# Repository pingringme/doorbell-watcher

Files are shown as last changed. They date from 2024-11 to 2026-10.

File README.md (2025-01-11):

# PingRing.me - Smart Doorbell

## 🌟 About PingRing.me

PingRing.me modernizes your existing doorbell by adding notifications via SMS, WhatsApp, HTTP, MQTT, and more. This enhancement ensures you never miss a visitor, whether you're outside or wearing noise-canceling headphones. The system integrates seamlessly with your current doorbell setup, allowing you to track arrivals and receive timely notifications.

## 🛠️ Features

- **Multi-Channel Notifications:** Receive alerts through SMS, WhatsApp, HTTP, MQTT, etc.
- **Seamless Integration:** Compatible with existing doorbell systems.
- **Local Web Server:** Access device information and perform over-the-air updates.
- **Open Source:** Hardware designs and code are publicly available.

## 📸 Visuals

Check [website here https://pingring.me](https://pingring.me)

## 🛠️ Tech Stack

- **Microcontroller:** ESP32-PICO-D4
- **Programming Language:** C (Arduino)
- **Cloud Functions:** AWS Lambda (Python)
- **Hardware Platform:** [TinyPICO USB-C](https://www.tinypico.com)

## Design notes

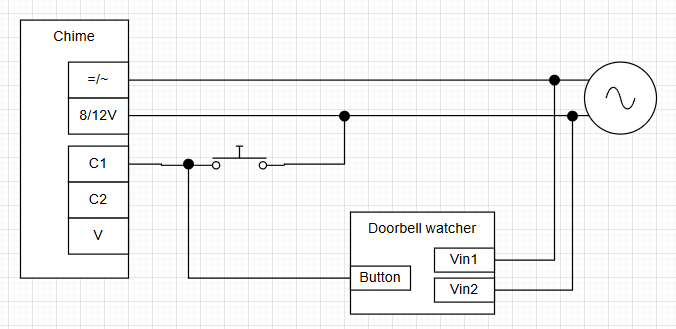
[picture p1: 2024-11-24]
docs/system_diagram.png

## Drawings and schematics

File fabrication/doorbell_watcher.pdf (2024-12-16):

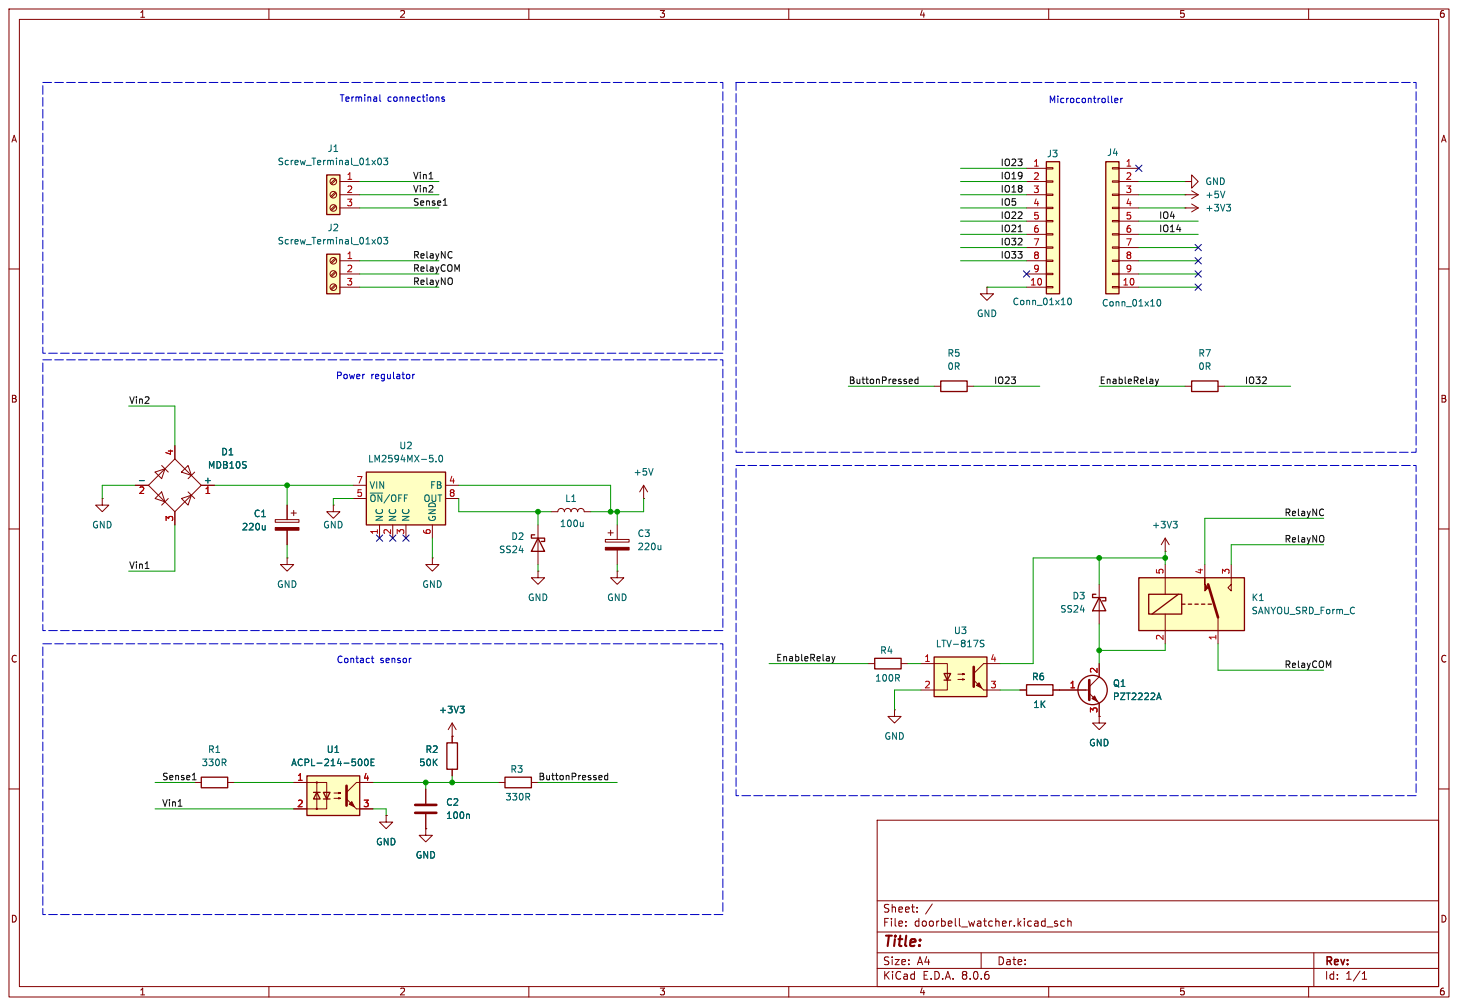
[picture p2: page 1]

3 FB 4 ~{ON}/OFF 5 GND

Id: 1/1 Title: File: doorbell_watcher.kicad_sch Sheet: /

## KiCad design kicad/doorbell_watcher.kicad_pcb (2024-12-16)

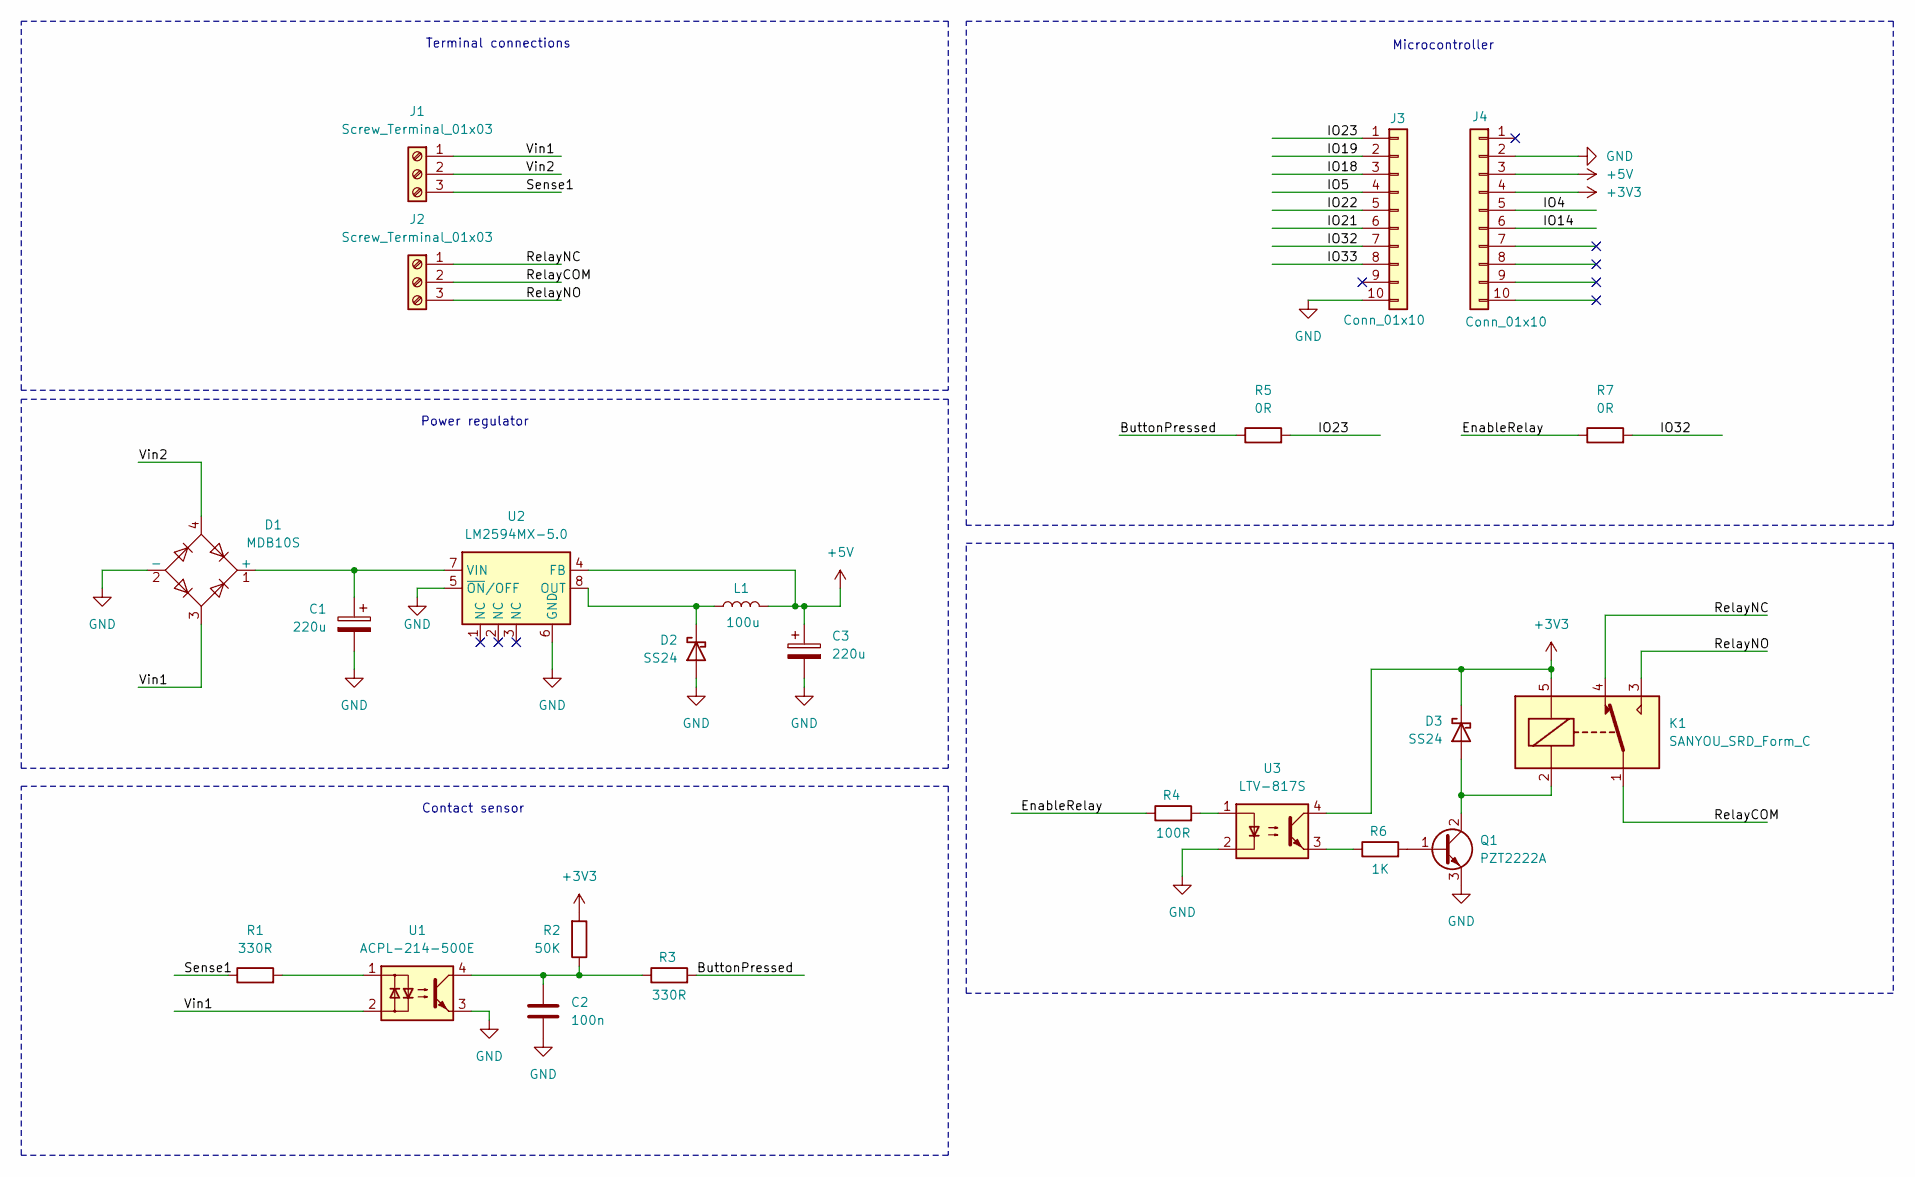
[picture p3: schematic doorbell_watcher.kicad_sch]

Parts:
C1, C3: 220u; CAP_FT_F_PAN-M; LCSC C178594
C2: 100n; C_0805_2012Metric_Pad1.18x1.45mm_HandSolder; LCSC C49678
D1: MDB10S; TSSOP4-MICRO-DIP_948BS_ONS-M; LCSC C258169
D2, D3: SS24; DO-214AC(SMA); LCSC C211773
J1, J2: Screw_Terminal_01x03; screw_connector_1x3; LCSC C589616
J3, J4: Conn_01x10; 10-pin header; LCSC C225507
K1: SANYOU_SRD_Form_C; Relay_SPDT_SANYOU_SRD_Series_Form_C; LCSC C24585
L1: 100u; IND_829SNLT_PUL; LCSC C2453068
Q1: PZT2222A; SOT-223-3_TabPin2; LCSC C115272
R1, R3: 330R; R_0805_2012Metric_Pad1.20x1.40mm_HandSolder; LCSC C17630
R2: 50K; R_0805_2012Metric_Pad1.20x1.40mm_HandSolder; LCSC C2828840
R4: 100R; R_0805_2012Metric_Pad1.20x1.40mm_HandSolder; LCSC C17408
R5, R7: 0R; R_0805_2012Metric_Pad1.20x1.40mm_HandSolder; LCSC C17477
R6: 1K; R_0805_2012Metric_Pad1.20x1.40mm_HandSolder; LCSC C95781
U1: ACPL-214-500E; SOP-4_4.4x2.6mm_P1.27mm; LCSC C5361360
U2: LM2594MX-5.0; SOIC-8_3.9x4.9mm_P1.27mm; LCSC C35323
U3: LTV-817S; SMDIP-4_W9.53mm; LCSC C125121

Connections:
+3V3: D3.1 (K), J4.4, K1.5, R2.2, U3.4
+5V: C3.1, J4.3, L1.2, U2.4 (FB)
/ButtonPressed: R3.2, R5.1
/EnableRelay: R4.1, R7.1
/IO4: J4.5
/IO5: J3.4
/IO14: J4.6
/IO18: J3.3
/IO19: J3.2
/IO21: J3.6
/IO22: J3.5
/IO23: J3.1, R5.2
/IO32: J3.7, R7.2
/IO33: J3.8
/RelayCOM: J2.2, K1.1
/RelayNC: J2.1, K1.4
/RelayNO: J2.3, K1.3
/Sense1: J1.3, R1.1
/Vin1: D1.3, J1.1, U1.2
/Vin2: D1.4, J1.2
GND: C1.2, C2.2, C3.2, D1.2 (-), D2.2 (A), J3.10, J4.2, Q1.3 (E), U1.3, U2.5 (~ON/OFF), U2.6 (GND), U3.2
unnamed: C2.1, R2.1, R3.1, U1.4
unnamed: C1.1, D1.1 (+), U2.7 (VIN)
unnamed: D2.1 (K), L1.1, U2.8 (OUT)
unnamed: D3.2 (A), K1.2, Q1.2 (C)
unnamed: Q1.1 (B), R6.2
unnamed: R1.2, U1.1
unnamed: R4.2, U3.1
unnamed: R6.1, U3.3

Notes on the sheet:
Contact sensor
Terminal connections
Microcontroller
Power regulator

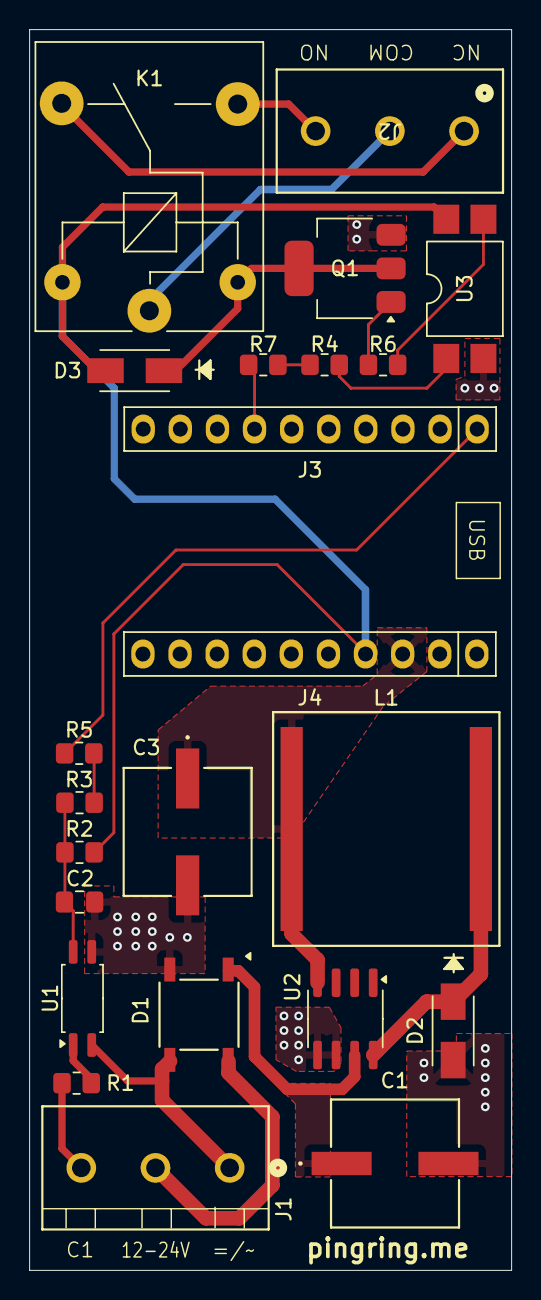
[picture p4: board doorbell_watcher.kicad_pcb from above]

Board: 2 copper layers, 33.0 x 84.9 mm, 23 parts (0 on the bottom side), 21 nets.

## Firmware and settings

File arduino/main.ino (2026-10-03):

#include <HTTP_Method.h>
#include <Uri.h>
#include <NetworkClient.h>
#include <TinyPICO.h>
#include <WiFi.h>
#include <WebServer.h>
#include <HTTPClient.h>
#include <ESPmDNS.h>
#include <ElegantOTA.h>
#include <PubSubClient.h>
#include <WiFiClientSecure.h>
#include "esp_netif.h"
#include "time.h"
#include "config.h"

// (all configuration constants are now defined in config.h)

// instances
TinyPICO tp = TinyPICO();
WebServer server(80);
WiFiClient espClient;
PubSubClient mqttClient(espClient);

// variables
IPAddress mqttServerIP;
// Fixed-size buffers (no heap allocation): "YYYY-MM-DD HH:MM:SS" = 19 chars
// + null terminator + safety margin.
char startupDateTime[24] = "n/a";
char lastRelayDateTime[24] = "never";
bool isConfigured = false;
int mqttRetries = 0;
int wifiRetries = 0;
int bellPresses = 0;
int mqttDiscoverySent = 0;
bool isSilenced = false;
unsigned long lastRelayTime = 0;
unsigned long lastHttpTime = 0;
unsigned long lastMqttReconnectAttempt = 0;
int relayActivations = 0;
// Mirror-mode relay state: while the physical bell button is held down, the
// relay is held HIGH. These are written by relaySetOn/relaySetOff (called
// from pollBellButton) and read by the safety force-off check.
bool relayOn = false;
unsigned long relayOnSince = 0;
// Deferred-HTTP flag: set on a press edge when the cooldown allows it, and
// consumed AFTER pollBellButton() so the release edge can be observed before
// the blocking HTTPS call is made. This keeps short presses from holding the
// relay on for the full HTTP timeout window.
bool httpSendPending = false;

String getMacAddress() {
    uint8_t mac[6];
    WiFi.macAddress(mac); // Get MAC address as an array
    
    // Convert MAC array to string format
    char macStr[18];
    snprintf(macStr, sizeof(macStr), "%02X:%02X:%02X:%02X:%02X:%02X",
             mac[0], mac[1], mac[2], mac[3], mac[4], mac[5]);

    return String(macStr);
}

String getTimeString() {
    struct tm timeinfo;
    if (!getLocalTime(&timeinfo)) {
        return "Failed to obtain time";
    }

    char timeStr[16];
    strftime(timeStr, sizeof(timeStr), "%H:%M:%S", &timeinfo);
    
    return String(timeStr);
}

String getDateString() {
    struct tm timeinfo;
    if (!getLocalTime(&timeinfo)) {
        return "Failed to obtain date";
    }

    char dateStr[16];
    strftime(dateStr, sizeof(dateStr), "%Y-%m-%d", &timeinfo); // Format: YYYY-MM-DD

    return String(dateStr);
}

String getFreeMemoryString() {
    int freeHeap = ESP.getFreeHeap();  // Get free heap memory in bytes
    return String(freeHeap);
}

// Block (up to timeoutMs) until the system clock has been synced via NTP.
// Returns true if time was obtained.
bool waitForTimeSync(uint32_t timeoutMs) {
    struct tm timeinfo;
    return getLocalTime(&timeinfo, timeoutMs);
}

// Fill a fixed-size buffer with the current local date+time as
// "YYYY-MM-DD HH:MM:SS". Falls back to "n/a" if the clock is not synced.
// Avoids any heap allocation, so it's safe to call indefinitely.
void fillDateTimeString(char* buf, size_t bufSize) {
    struct tm timeinfo;
    if (!getLocalTime(&timeinfo)) {
        snprintf(buf, bufSize, "n/a");
        return;
    }
    strftime(buf, bufSize, "%Y-%m-%d %H:%M:%S", &timeinfo);
}

// DHCP lease renewals overwrite DNS, so this is re-applied before every HTTPS request.
void applyDnsOverride() {
  IPAddress primary, secondary;
  if (!primary.fromString(dns_override_primary)) {
    return;
  }
  esp_netif_dns_info_t dns = {};
  dns.ip.type = ESP_IPADDR_TYPE_V4;
  dns.ip.u_addr.ip4.addr = static_cast<uint32_t>(primary);
  esp_netif_set_dns_info(WiFi.STA.netif(), ESP_NETIF_DNS_MAIN, &dns);
  if (secondary.fromString(dns_override_secondary)) {
    dns.ip.u_addr.ip4.addr = static_cast<uint32_t>(secondary);
    esp_netif_set_dns_info(WiFi.STA.netif(), ESP_NETIF_DNS_BACKUP, &dns);
  }
}

void setup() {
  // booting up with blue as initial color
  tp.DotStar_SetPixelColor(0, 0, 255);  //Blue
  // serial setup
  Serial.begin(115200);
  Serial.println("*************");
  Serial.println("Booting up...");
  // pins setup
  configureIO();
  // wifi setup
  watchWifi();
  // mDNS
  configureMDNS();
  // mqtt
  configureMQTT();
  // web server
  configureWebServer();
  // configure time
  configTime(gmtOffset_sec, daylightOffset_sec, ntpServer);
  // wait for NTP to actually sync before stamping startupDateTime; otherwise
  // the stored value would be "Failed to obtain ..." on a cold boot.
  if (!waitForTimeSync(NTP_SYNC_TIMEOUT_MS)) {
    Serial.println("Warning: NTP sync timed out.");
  }
  // standard initial sleep...
  Serial.println("finishing initial setup()...");
  // print time
  fillDateTimeString(startupDateTime, sizeof(startupDateTime));
  Serial.println(startupDateTime);
  // delay after setup
  delay(SLEEP_AFTER_SETUP_MS);
  // release
  isConfigured = true;
}
String enabledBadge(bool enabled) {
  return enabled ? "<span class=\"badge bg-success\">enabled</span>"
                 : "<span class=\"badge bg-secondary\">disabled</span>";
}

// "***" is the placeholder used for secrets in the committed config.h.
bool isSecretSet(const char* value) {
  return strlen(value) > 0 && strcmp(value, "***") != 0;
}

// base URL handling
void handle_base() {
  Serial.println("ESP32 Web Server: New request received...");  // for debugging
  Serial.println("GET /");                                      // for debugging
 
  // response
  String page = html_template_main;
  // variables 
  page.replace("{{firmware}}", FIRMWARE_VERSION);
  page.replace("{{startup}}", startupDateTime);
  page.replace("{{now}}", getDateString() + " "+ getTimeString());
  page.replace("{{heap}}", getFreeMemoryString());

  page.replace("{{ssid}}", WiFi.SSID());
  page.replace("{{ip}}", WiFi.localIP().toString());
  page.replace("{{rssi}}", String(WiFi.RSSI()) + " dBm");
  page.replace("{{mac}}", getMacAddress());
  page.replace("{{dns}}", WiFi.dnsIP(0).toString() + ", " + WiFi.dnsIP(1).toString() +
                          (strlen(dns_override_primary) > 0 ? " (override)" : " (DHCP)"));

  page.replace("{{mqtt_server}}", "mqtt://" + String(mqtt_auth_user) + ":***@" + mqttServerIP.toString() + ":" + String(mqtt_port));
  page.replace("{{mqtt_connected}}", mqttClient.connected() ? "true" : "false");
  page.replace("{{mqtt_retries}}", String(mqttRetries));
  page.replace("{{mqtt_discovery}}", String(mqttDiscoverySent));

  page.replace("{{wifi_retries}}", String(wifiRetries));
  page.replace("{{bell_presses}}", String(bellPresses));
  page.replace("{{relay_activations}}", String(relayActivations));
  page.replace("{{relay_last}}", lastRelayDateTime);
  page.replace("{{silence_mode}}", isSilenced ? "true" : "false");

  page.replace("{{cfg_mqtt}}", enabledBadge(mqtt_enabled));
  page.replace("{{cfg_aws}}", enabledBadge(notify_aws_enabled));
  page.replace("{{cfg_telegram}}", enabledBadge(notify_telegram_enabled));
  page.replace("{{cfg_telegram_token}}", isSecretSet(TELEGRAM_BOT_TOKEN) ? "set" : "missing");
  page.replace("{{cfg_telegram_chat}}", isSecretSet(TELEGRAM_CHAT_ID) ? TELEGRAM_CHAT_ID : "missing");
 
  // never cache this status page: values change constantly
  server.sendHeader("Cache-Control", "no-store");
  server.send(200, "text/html", page);
}

// silence mode URL handling
void handle_silence() {
  Serial.println("ESP32 Web Server: Toggling silence...");
  Serial.println("GET /silence");
  // send browser/client result
  server.send(200, "application/json", "{\"action\":\"silence\",\"result\":true}");
  // switch settings
  toggleSilence();
}

// relay URL handling
void handle_relay() {
  Serial.println("ESP32 Web Server: Activating relay...");
  Serial.println("GET /relay");
  // send browser/client result
  server.send(200, "application/json", "{\"action\":\"relay\",\"result\":true}");
  // relay trigger (fixed-duration pulse: no physical press to mirror)
  pulseRelay();
}
// button URL handling
void handle_button() {
  Serial.println("ESP32 Web Server: Activating button...");
  Serial.println("GET /button");
  // send browser/client result
  server.send(200, "application/json", "{\"action\":\"button\",\"result\":true}");
  // button trigger
  activateButton("http");
}
// not found
void handle_NotFound() {
  server.send(404, "text/plain", "Not found");
}
void handle_restart() {
  Serial.println("arduino/esp32 - restart requested...");
  ESP.restart();
}
// Resolve the broker hostname via mDNS. Returns true if a valid (non-zero) IP
// was obtained. mqttServerIP is updated either way.
bool resolveMqttBroker() {
  if (strlen(mqtt_server_hostname_mdns) == 0 || mqtt_port <= 0) {
    return false;
  }
  mqttServerIP = MDNS.queryHost(mqtt_server_hostname_mdns);
  if (mqttServerIP == IPAddress(0, 0, 0, 0)) {
    Serial.print("mDNS lookup failed for ");
    Serial.println(mqtt_server_hostname_mdns);
    return false;
  }
  Serial.print("MQTT broker resolved: ");
  Serial.println(mqttServerIP);
  return true;
}

// Shared Home Assistant MQTT discovery "device" sub-object. Identical
// across every entity belonging to this device, so factored out to keep
// the discovery payloads honest about that fact.
static String mqttDeviceObject() {
  return String("\"device\":{\"identifiers\":[\"") + mqtt_device_id +
         "\"],\"manufacturer\":\"PingRing.me\",\"model\":\"PingRing Board\",\"name\":\"PingRing\"}";
}

// Publish Home Assistant MQTT discovery payloads. Caller must ensure the
// client is connected.
void publishMqttDiscovery() {
  String discovery_payload;
  // discovery for STATE
  discovery_payload = "{";
  discovery_payload += "\"name\": \"Doorbell\",";
  discovery_payload += "\"unique_id\": \"" + String(mqtt_unique_id) + "\",";
  discovery_payload += "\"state_topic\": \"" + String(mqtt_topic_state) + "\",";
  discovery_payload += "\"json_attributes_topic\": \"" + String(mqtt_topic_attributes) + "\",";
  discovery_payload += "\"device_class\": \"occupancy\",";
  discovery_payload += "\"payload_on\": \"ON\",";
  discovery_payload += "\"payload_off\": \"OFF\",";
  discovery_payload += "\"availability_topic\": \"" + String(mqtt_topic_availability) + "\",";
  discovery_payload += "\"payload_available\": \"online\",";
  discovery_payload += "\"payload_not_available\": \"offline\",";
  discovery_payload += mqttDeviceObject();
  discovery_payload += "}";
  mqttClient.publish(mqtt_topic_discovery_state, discovery_payload.c_str(), true);
  mqttDiscoverySent++;
  // discovery for COUNT
  discovery_payload = "{";
  discovery_payload += "\"name\": \"Presses\",";
  discovery_payload += "\"unique_id\": \"" + String(mqtt_unique_id) + "_count\",";
  discovery_payload += "\"state_topic\": \"" + String(mqtt_topic_count) + "\",";
  discovery_payload += "\"unit_of_measurement\": \"presses\",";
  discovery_payload += "\"state_class\": \"total_increasing\",";
  discovery_payload += mqttDeviceObject();
  discovery_payload += "}";
  mqttClient.publish(mqtt_topic_discovery_count, discovery_payload.c_str(), true);
  mqttDiscoverySent++;
}

// Non-blocking connect/reconnect attempt. Rate-limited via
// MQTT_RECONNECT_INTERVAL_MS. Returns true if connected after the call.
bool ensureMqttConnected() {
  if (!mqtt_enabled) {
    return false;
  }
  if (mqttClient.connected()) {
    return true;
  }
  unsigned long now = millis();
  if (lastMqttReconnectAttempt != 0 &&
      (now - lastMqttReconnectAttempt) < MQTT_RECONNECT_INTERVAL_MS) {
    return false;
  }
  lastMqttReconnectAttempt = now;

  // Re-resolve the broker every time we attempt to reconnect; the IP may
  // have changed and the previous lookup may have failed.
  if (!resolveMqttBroker()) {
    return false;
  }
  mqttClient.setServer(mqttServerIP, mqtt_port);
  mqttClient.setBufferSize(1024);

  mqttRetries++;
  Serial.print("MQTT connecting (attempt ");
  Serial.print(mqttRetries);
  Serial.println(")...");
  if (!mqttClient.connect(mqtt_device_id, mqtt_auth_user, mqtt_auth_pass,
                          mqtt_topic_availability, 0, true, "offline")) {
    Serial.print("MQTT connect failed, state=");
    Serial.println(mqttClient.state());
    return false;
  }
  mqttClient.publish(mqtt_topic_availability, "online", true);
  publishMqttDiscovery();
  Serial.println("MQTT connected and discovery sent!");
  return true;
}

void configureMQTT() {
  if (!mqtt_enabled) {
    Serial.println("MQTT service is not enabled.");
    return;
  }
  // First connection attempt; subsequent reconnects happen from loop().
  ensureMqttConnected();
}
void configureWebServer() {
  // registering two routes...
  Serial.println("Creating web routes...");
  // default
  server.on("/", handle_base);
  // registering /silence for toggling silence mode
  server.on("/silence", handle_silence);
  // registering /relay for relay trigger
  server.on("/relay", handle_relay);
  // registering /button for button trigger
  server.on("/button", handle_button);
  // registering /notify?backend=<aws|telegram> for a test notification
  server.on("/notify", handle_notify);
  // registering /restart for arduino&esp32 restart
  server.on("/restart", handle_restart);
  // not found
  server.onNotFound(handle_NotFound);
  // installing OTA feature
  ElegantOTA.begin(&server);
  // start web server
  server.begin();
  Serial.println("HTTP server started");
}
void configureIO() {
  // setting pin as input. External pullup is present on the board; the
  // internal pullup is enabled too as a defensive backup (they parallel,
  // no conflict).
  pinMode(bellButtonPin, INPUT_PULLUP);
  pinMode(bellRelayPin, OUTPUT);
  digitalWrite(bellRelayPin, LOW);
}
void configureMDNS() {
    // starting mDNS
    if (!MDNS.begin(hostname)) {
      Serial.println("Error setting up mDNS responder!");
    } else {
      Serial.println("mDNS responder started.");
    }
}
void watchWifi() {
  // (re-)cconnecting to the wifi, if needed.
  if (WiFi.status() != WL_CONNECTED) {
    // initial config
    WiFi.setSleep(false);
    WiFi.setAutoReconnect(true);
    WiFi.setHostname(hostname);
    // logging....
    Serial.println("Wifi is not connected....");
    // making sure wifi is connected
    while (WiFi.status() != WL_CONNECTED) {
      // blink a few times (white/yellow)
      blinkYellow(3);
      // increase counter
      wifiRetries++;
      // logging
      Serial.print("Attempting to connect to SSID: ");
      Serial.print(ssid);
      Serial.println(" (" + String(wifiRetries) + ").");
      // Connect to WPA/WPA2 network. Change this line if using open or WEP network:    
      WiFi.begin(ssid, password);
      // wait X seconds after wifi connection:
      delay(SLEEP_AFTER_WIFI_RETRY_MS);
    }
    // set green LED
    tp.DotStar_SetPixelColor(0, 128, 0);  //Green
    // logging...
    printWifiInfo();
    applyDnsOverride();

  }
}
void printWifiInfo() {
  Serial.print("Connected to WiFi network with IP Address: ");
  Serial.println(WiFi.localIP());
  Serial.print("Wifi Status:");
  Serial.println(WiFi.status());
}

// Shared blink primitive: flash (r1,g1,b1), hold 75ms, then settle on
// (r2,g2,b2). Repeats `count` times. The settle color is the resting
// state the caller wants to leave the LED in.
static void blinkPattern(uint8_t r1, uint8_t g1, uint8_t b1,
                         uint8_t r2, uint8_t g2, uint8_t b2,
                         int count) {
  while (count-- > 0) {
    tp.DotStar_SetPixelColor(r1, g1, b1);
    delay(75);
    tp.DotStar_SetPixelColor(r2, g2, b2);
  }
}

void blinkPurple(int count) { blinkPattern(128, 0, 128,   0, 128, 0,   count); } // press feedback, settle on green
void blinkYellow(int count) { blinkPattern(255, 255, 255, 255, 255, 0, count); } // wifi retry, settle on yellow

void publishMqttState(const char* source, const char* state, bool sendAttributes) {

  if (!mqtt_enabled) {
    return;
  }
  if (!mqttClient.connected()) {
    Serial.println("MQTT not connected, skipping publish.");
    return;
  }

  // Publish bell state
  mqttClient.publish(mqtt_topic_state, state);
  mqttClient.publish(mqtt_topic_count, String(bellPresses).c_str(), true); // retain - to be able to see it later :)

  // should we send attributes?
  if (sendAttributes) {
    // Build JSON attributes
    String payload = "{";
    payload += "\"source\":\"" + String(source) + "\",";
    payload += "\"event\":\"pressed\",";
    payload += "\"is_silenced\":" + String(isSilenced ? "true" : "false") + ",";
    payload += "\"bell_counter\":" + String(bellPresses);
    payload += "}";
    // publishing attributes
    mqttClient.publish(mqtt_topic_attributes, payload.c_str(), false);
  }
}

// ---------------------------------------------------------------------------
// Notification backends
// ---------------------------------------------------------------------------
// Each backend is a small self-contained function that performs one HTTPS
// request. dispatchNotifications() fans out to every enabled backend in
// sequence. Backends are gated by runtime flags in config.h
// (notify_aws_enabled, notify_telegram_enabled); disabled ones skip the
// HTTPS call but still occupy flash.
//
// All backends share HTTP_TIMEOUT_MS, share the deferred-send mechanism
// (processPendingHttp), and share the post-press cooldown
// (SLEEP_HTTP_AFTER_BELL_MS). Total worst-case stall is roughly
// (#enabled_backends * HTTP_TIMEOUT_MS).

// Detail of the most recent httpsSend() failure; empty on success.
String lastHttpsError;

// Shared HTTPS request helper. Owns the WiFiClientSecure + HTTPClient
// lifetime so callers stay tiny. Pass body+contentType for POST, omit
// them (or pass empty/nullptr) for GET. Returns the HTTP response code,
// or a negative value on transport failure. Logs the response body when
// the request failed, to keep debugging usable without spamming the
// serial console on success.
static int httpsSend(const char* name, const String& url,
                     const char* method,
                     const String& body = String(),
                     const char* contentType = nullptr) {
  Serial.print(name); Serial.println(" request...");
  lastHttpsError = "";
  applyDnsOverride();
  uint32_t heapBefore = ESP.getFreeHeap();
  WiFiClientSecure client;
  client.setInsecure(); // replace with setCACert(...) to pin the CA
  HTTPClient http;
  http.setTimeout(HTTP_TIMEOUT_MS);
  if (!http.begin(client, url)) {
    lastHttpsError = "HTTP begin() failed (invalid URL?)";
    Serial.print(name); Serial.print(": "); Serial.println(lastHttpsError);
    return -1;
  }
  if (contentType) {
    http.addHeader("Content-Type", contentType);
  }
  int code = (strcmp(method, "POST") == 0) ? http.POST(body) : http.GET();
  Serial.print(name); Serial.print(" response: "); Serial.println(code);
  if (code < 0) {
    char tlsErr[100] = "";
    int tlsCode = client.lastError(tlsErr, sizeof(tlsErr));
    lastHttpsError = HTTPClient::errorToString(code) + "; tls " + tlsCode + ": " + tlsErr +
                     "; free heap before request: " + heapBefore;
  } else if (code >= 400) {
    lastHttpsError = http.getString();
  }
  if (lastHttpsError.length() > 0) {
    Serial.println(lastHttpsError);
  }
  http.end();
  return code;
}

static int sendAwsNotification(const char* source) {
  (void)source; // current Lambda contract is fully encoded in serverRequest
  return httpsSend("AWS", serverRequest, "GET");
}

// Percent-encode a String for safe inclusion in a URL querystring value.
// Keeps the RFC 3986 unreserved set; everything else becomes %HH. Avoids
// the +-for-space form (some clients render it literally). Local helper
// because arduino-esp32's upstream HTTPClient does not expose urlEncode
// in its public API.
static String urlEncode(const String& in) {
  static const char hex[] = "0123456789ABCDEF";
  String out;
  out.reserve(in.length() * 3);
  for (size_t i = 0; i < in.length(); ++i) {
    uint8_t c = (uint8_t)in[i];
    bool unreserved = (c >= '0' && c <= '9') ||
                      (c >= 'A' && c <= 'Z') ||
                      (c >= 'a' && c <= 'z') ||
                      c == '-' || c == '_' || c == '.' || c == '~';
    if (unreserved) {
      out += (char)c;
    } else {
      out += '%';
      out += hex[c >> 4];
      out += hex[c & 0x0F];
    }
  }
  return out;
}

static int sendTelegramNotification(const char* source) {
  String text = String("Doorbell ring (") + source + ") @ " +
                getDateString() + " " + getTimeString();
  String url  = String("https://api.telegram.org/bot") + TELEGRAM_BOT_TOKEN +
                "/sendMessage?chat_id=" + TELEGRAM_CHAT_ID +
                "&text=" + urlEncode(text);
  return httpsSend("Telegram", url, "GET");
}
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
void loop() {
  // wait for setup()
  if (!isConfigured) {
    delay(1000);
    return;
  }
  // monitor the wifi
  watchWifi();
  // monitor the bell (debounced)
  pollBellButton();
  // fire any deferred HTTP webhook from the most recent press edge.
  // Done AFTER pollBellButton() so a same-iteration release edge has
  // already turned the relay off before we block on the network.
  processPendingHttp();
  // handle HTML requests
  server.handleClient();
  // handle OTA and reboot
  ElegantOTA.loop();
  // keep MQTT alive and reconnect if needed
  ensureMqttConnected();
  mqttClient.loop();
  // sleep a bit...
  delay(MONITORING_INTERVAL_MS);
}

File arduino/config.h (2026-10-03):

#ifndef CONFIG_H
#define CONFIG_H

#include <Arduino.h>

#if __has_include("secrets.h")
#include "secrets.h"
#else
#error "Missing arduino/secrets.h: copy secrets.example.h to secrets.h and fill in your values."
#endif

// ---------------------------------------------------------------------------
// Firmware
// ---------------------------------------------------------------------------
#define FIRMWARE_VERSION "20261003222246"

// ---------------------------------------------------------------------------
// Timings (milliseconds)
// ---------------------------------------------------------------------------
#define RELAY_DURATION_MS            750    // how long the relay should be active when triggered via HTTP (/relay or /button), i.e. without a physical press to mirror
#define RELAY_MAX_ON_MS              3000   // hard safety cap: never hold the relay on for longer than this, even if the physical button is stuck or held forever
#define SLEEP_AFTER_SETUP_MS         2000   // wait this long after setup() before allowing button presses, to avoid issues during boot
#define SLEEP_RELAY_AFTER_BELL_MS    15000  // after a bell press, do not allow another relay activation for this long, even if the button is pressed again (debounce + cooldown)
#define SLEEP_HTTP_AFTER_BELL_MS     15000  // after a bell press, do not allow another HTTP request for this long
#define SLEEP_AFTER_WIFI_RETRY_MS    5000   // after a failed WiFi connection attempt, wait this long before retrying, to avoid spamming the network
#define MONITORING_INTERVAL_MS       25     // interval between loop() iterations. Kept well below DEBOUNCE_MS (50) so the debounce filter gets at least 2 samples per window. Also bounds release-edge detection latency.
#define DEBOUNCE_MS                  50     // bell button debounce window
#define NTP_SYNC_TIMEOUT_MS          10000  // wait up to this long for NTP at boot
#define MQTT_RECONNECT_INTERVAL_MS   5000   // do not retry more often than this
#define HTTP_TIMEOUT_MS              3000   // outbound HTTPS request timeout. Kept tight: while the request is in flight the main loop cannot poll the button, so this bounds the worst-case release-detection delay. Sized to fit the AWS Lambda fan-out (SMS + WhatsApp + email) typical latency.

// ---------------------------------------------------------------------------
// Notification backends
// ---------------------------------------------------------------------------
// Toggle each backend independently. Both can be enabled at once; they will
// be fired sequentially from processPendingHttp() / activateButton().
// Runtime flags (matches mqtt_enabled style). Both backends are always
// compiled into the binary; disabling one only skips the HTTPS call.
const bool notify_aws_enabled      = false;
const bool notify_telegram_enabled = false;

// Credentials and endpoints (WiFi, AWS Lambda, Telegram, MQTT password) live in secrets.h.

// ---------------------------------------------------------------------------
// NTP
// ---------------------------------------------------------------------------
const char* ntpServer           = "pool.ntp.org"; // public NTP pool; override with a LAN NTP server if available
const long  gmtOffset_sec       = 3600;           // base UTC offset in seconds (+1h Berlin / CET)
const int   daylightOffset_sec  = 3600;           // additional DST offset in seconds (+1h during summer time)

// ---------------------------------------------------------------------------
// WiFi
// ---------------------------------------------------------------------------
const char* hostname = "esp32-pingringme"; // advertised hostname + mDNS name (resolves as esp32-pingringme.local)
const char* ssid     = WIFI_SSID;
const char* password = WIFI_PASSWORD;
const char* dns_override_primary   = "8.8.8.8";   // empty = use the router's DNS (DHCP)
const char* dns_override_secondary = "1.1.1.1";   // only used if primary is set
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

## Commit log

2024-11-24 Add power stage simulation and first schematic draft.
    [doorbell_watcher.kicad_pcb, doorbell_watcher.kicad_sch]
2024-11-24 Added button signal simulation. Schematic is complete.
    [doorbell_watcher.kicad_sch]
2024-11-25 Placement done
    [doorbell_watcher.kicad_pcb, doorbell_watcher.kicad_sch]
2024-11-26 Routing complete, changed LM2596 to LM2594
    [doorbell_watcher.kicad_pcb, doorbell_watcher.kicad_sch]
2024-11-26 Added fabrication files
    [doorbell_watcher-B_Cu.gbr, doorbell_watcher-B_Mask.gbr, doorbell_watcher-B_Paste.gbr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]
2024-11-27 First fabrication release done
    [doorbell_watcher-B_Cu.gbr, doorbell_watcher-B_Mask.gbr, doorbell_watcher-B_Paste.gbr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]
2024-11-29 Fix MDB9S footprint
    [doorbell_watcher-B_Cu.gbr, doorbell_watcher-B_Mask.gbr, doorbell_watcher-B_Paste.gbr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]
2024-12-11 Fix unconnected 5V pin in ESP32 header
    [doorbell_watcher-B_Cu.gbr, doorbell_watcher-B_Mask.gbr, doorbell_watcher-B_Paste.gbr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]
2024-12-12 Adding my arduino sketch code
2024-12-16 Add relay
    [doorbell_watcher-B_Cu.gbr, doorbell_watcher-B_Mask.gbr, doorbell_watcher-B_Paste.gbr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]
2025-01-09 fixing potential wifi reconnecting issues, adding OTA, bell counter and NTP time.
    [main.ino]
2025-07-19 fix: avoid sleeping the device after bell :)
    [main.ino]
2025-11-26 feat: enhance HTML template, implementing Bootstrap5
    improved HTML template for device status :)
2026-05-17 feat: Extract configuration to config.h
    Add a new arduino/config.h and move all configuration constants out of main.ino. The header introduces header guards and contains firmware/version, timing values, HTTP/WiFi/MQTT settings, NTP, pins, 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
2026-05-17 Improve MQTT/HTTP, add debounce & UI fixes
    Multiple improvements and fixes across Arduino firmware:
    - Added DEBOUNCE_MS and implemented pollBellButton() for software debouncing of the bell GPIO.
    - Wait for NTP sync at boot (with timeout) before stamping startup time.
    - Enhance MQTT handling: add mDNS broker resolution, rate-limited non-blocking reconnects (ensureMqttConnected), last-reconnect tracking, and separated publishMqttDiscovery() to send Home Assistant discovery payloads. Skip publishes when not connected.
    - Fix JSON HTTP responses (send valid JSON strings) and add Cache-Control: no-store on status page. Add RSSI units to the UI.
    - Use WiFiClientSecure for outbound HTTPS requests,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
    [config.h, main.ino]
2026-05-17 Track relay activations and extend duration
    Increase relay pulse from 500ms to 750ms and add runtime observability for relay usage. Introduces relayActivations counter and lastRelayDateTime string (initialized to "never"); increments the count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
2026-05-17 fix: Bump firmware; adjust timings, UI and IO
    Bump FIRMWARE_VERSION and shorten various sleep intervals for faster responsiveness (setup, relay-after-bell and HTTP-after-bell). Remove URL scheme from HTTP_SERVER_URL placeholder. Update web UI headings to use h2.h4 for consistent styling and add a "Restart Device" button. Enable internal INPUT_PULLUP for the bell input pin (defensive backup to existing external pull-up) and remove a redundant post-relay delay to avoid an extra wait after toggling the relay.
    [config.h, main.ino]
2026-05-17 fix: Use fixed buffers for datetimes & tweak bell logic
    Bump firmware version and refactor datetime handling to use fixed-size char buffers (no heap allocations) via fillDateTimeString(). Replace String-based timestamps with startupDateTime and lastRelayDateTime char arrays. Introduce lastRelayTime and lastHttpTime to track actual relay/HTTP events so cooldown logic is based on real activations; lastRelayTime is updated only when the relay fires. Adjust debounce/cooldown behavior and comments for clarity, reduce LED blink delays (100->75ms), and change blinkPurple call count. Update WiFi retry interval and expand monitoring comments. Update web UI grid markup to use responsive row-cols and s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
    [config.h, main.ino]
2026-05-19 feat: Mirror-mode relay control and max-on safety
    Introduce mirror-mode relay state and safety cap to avoid GPIO contention and stuck relay situations. Added RELAY_MAX_ON_MS to config.h. In main.ino, add relayOn/relayOnSince state and non-blocking relaySetOn()/relaySetOff() used by the physical-button mirror path, plus pulseRelay() for fixed-duration HTTP-triggered pulses. Rework pollBellButton() to debounce, mirror the relay to the physical button (hold while pressed), enforce a max-on force-off, and handle press/release edges with relay actions performed before network I/O. Update activateButton() and HTTP handler to use pulseRelay() and adjust logging and cooldown logic accordingly.
    Tigh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
    [config.h, main.ino]
2026-05-19 feat: Bump firmware version; reduce monitoring interval
    Update arduino/config.h: bump FIRMWARE_VERSION timestamp and lower MONITORING_INTERVAL_MS from 100 to 25 ms. The shorter monitoring interval ensures at least two samples per DEBOUNCE_MS window and improves release-edge detection latency for more responsive button handling.
    [config.h]
2026-05-19 feat: Add Telegram + AWS notifications, refactor HTTP
    Bump firmware version and introduce pluggable notification backends (NOTIFY_AWS_ENABLED, NOTIFY_TELEGRAM_ENABLED) and Telegram config (TELEGRAM_BOT_TOKEN, TELEGRAM_CHAT_ID) in config.h. Factor out a shared mqttDeviceObject() for Home Assistant discovery payloads. Consolidate LED helpers into blinkPattern() with small wrappers blinkPurple()/blinkYellow(). Replace sendHttpRequest() with a generic httpsSend() helper and add sendAwsNotification()/sendTelegramNotification() plus dispatchNotifications() to fan out notifications sequentially. Hook dispatchNotifications() into activateButton() and processPendingHttp(), preserving the existing coo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
    [config.h, main.ino]
2026-05-19 fix: HTTPClient::urlEncode is not available in arduino :( Use local urlEncode for Telegram; bump firmware
    Add a local RFC3986-compliant urlEncode(String) helper and use it to percent-encode Telegram message text (avoids '+' for spaces and works around arduino-esp32 HTTPClient not exposing urlEncode). Also update FIRMWARE_VERSION timestamp. The encoder preserves unreserved characters and percent-encodes all others.
    [config.h, main.ino]
2026-05-19 fix: Use runtime notify flags; expand config docs
    Replace compile-time NOTIFY_AWS/TELEGRAM macros with runtime booleans (notify_aws_enabled, notify_telegram_enabled). Update dispatchNotifications to check those runtime flags instead of #if guards, and leave sendAws/sendTelegram functions unguarded so backends are compiled but skipped at runtime. Add and clarify comments throughout config.h (HTTP endpoint/security, WiFi, NTP, MQTT topics/ids, pins) and note server URL assembly. Also bump firmware version timestamp.
    [config.h, main.ino]
2026-10-03 feat: Add notification test hooks
    This change adds a status panel to the web UI and a /notify endpoint that can trigger a real AWS Lambda or Telegram test send without altering the enabled backend flags. It also wires the configurati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
2026-10-03 feat: Add DNS override and response logging
    Add configurable primary/secondary DNS overrides for the ESP32 station interface and reapply them before HTTPS requests so DHCP renewals do not break outbound notifications. Improve the web UI by showing current DNS settings, preserving action responses in a log panel, and returning detailed notify errors for easier debugging. Also treat placeholder Telegram secrets as missing in the status page.
    [config.h, main.ino]
2026-10-03 fix: Move firmware secrets into gitignored config
    This change moves sensitive WiFi, Lambda, Telegram, and MQTT credentials out of the main firmware config into a git-ignored `arduino/secrets.h` include. It adds a `secrets.example.h` template for local setup, updates `config.h` to fail fast when secrets are missing, and keeps the public config file free of private values.
    [config.h]
